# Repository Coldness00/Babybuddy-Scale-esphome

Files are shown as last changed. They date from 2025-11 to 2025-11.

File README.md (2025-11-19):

# 🍼 Smart Baby Bottle Scale  
### Measure every feeding automatically — ESP32 + ESPHome + Home Assistant + BabyBuddy  
<div align="center">
  
**Fully 3D‑printed • Open‑source • Wifi‑connected • Accurate to the gram**

</div>

---

## 🎯 Overview

This project is a **smart baby bottle scale** built with:

- an **ESP32‑S3**,  
- an **HX711 load cell amplifier**,  
- a **load cell**,  
- an **OLED display**,  
- RGB LEDs,  
- and **ESPHome**.

It automatically measures how much your baby drinks and sends the result directly to **Home Assistant**, which then creates a feeding entry in **BabyBuddy**.

Everything is fully autonomous, compact, and 3D‑printed.

---

## 🧩 Features

- **Accurate milk consumption tracking** (using calibrated load cell + HX711)
- **Automatic BabyBuddy feeding logs** through Home Assistant
- 3D‑printed enclosure (Bambu Studio `.3mf` included)
- **OLED screen** showing:
  - Bottle weight
  - Consumption
  - Last feeding time
  - Time since last feeding  
- **RGB LED feedback**
  - White fade in → bottle placed  
  - Yellow fade out → feeding started  
  - Green fade out → feeding finished  
  - Red pulse → error or invalid state  
- **Two physical buttons**
  - FULL → marks the bottle before feeding
    When pressed a circle is drawn on the top right corner of the screen
  - EMPTY → marks the bottle after feeding
  - When pressed the circle on the top right corner of the screen disappears
- **Static IP + fallback Wi‑Fi AP**
- **State restored after reboot** (timestamps, full weight, etc.)

---

## 🛒 Bill of Materials (BOM)

### Electronics

| Item | Description | Link |
|---|---|---|
| Load Cell + HX711 Kit | 50kg scale sensor with amplifier | https://fr.aliexpress.com/item/1005006165499175.html |
| ESP32‑S3 DevKitC‑1 | Main controller running ESPHome | - |
| SSD1306 OLED (128×64) | I²C display | https://fr.aliexpress.com/item/1005006262908701.html |
| WS2812 RGB LED strip | 3 LEDs | — |
| 2× Momentary push buttons | FULL + EMPTY | — |
| 8× M3 screws | — |

### 3D‑Printed Parts
- Complete `.3mf` Bambu Studio project included
- https://makerworld.com/en/models/2016578-babybuddy-scale#profileId-2172857
- Supports:
  - Load cell mount  
  - Front panel for OLED + buttons  
  - Compartment for ESP32 + HX711  



---

## 📸 Photos  





---

## 📡 How It Works

### 1. Press **FULL** before feeding  
- Weight is stored as “full bottle”  
- Timestamp saved  
- Yellow LED effect  
- Display shows full bottle icon  

### 2. Press **EMPTY** after feeding  
- New weight measured  
- Consumption is calculated  
- Data is sent to Home Assistant  
- Green LED effect  

### 3. Home Assistant Automation  
Home Assistant receives the values and automatically calls the **BabyBuddy API** to create a feeding entry (Formula / Bottle).

---

## 📦 ESPHome YAML Configuration

Full ESPHome config used in this project is available here:

`/esphome/biberon.yaml`

It includes:
- I²C OLED setup  
- HX711 calibration table  
- RGB LED effects  
- State persistence  
- Two GPIO buttons (full/empty)  
- Consumption calculation logic  
- Timestamp handling via Home Assistant time source  

---

## 🏠 Home Assistant Automation

Place this YAML inside your HA automations and edit accordingly the device_id:

```yaml
alias: Baby feeding bottle
description: ""
triggers:
  - trigger: state
    entity_id: sensor.biberon_bottle_consumption

conditions:
  - condition: template
    value_template: >
      {{ states('sensor.biberon_bottle_full_button_last_press') not in
         ['unknown','unavailable',''] and
         states('sensor.biberon_bottle_empty_button_last_press') not in
         ['unknown','unavailable',''] }}

  - condition: template
    value_template: >
      {{ states('sensor.biberon_bottle_consumption') | int(0) > 0 }}

actions:
  - delay: "00:00:02"
  - action: babybuddy.add_feeding
    target:
      device_id: 51762e63db1082c325ccfa7d02a4f4d6
    data:
      type: Formula
      method: Bottle
      start: "{{ states('sensor.biberon_bottle_full_button_last_press') }}"
      end: "{{ states('sensor.biberon_bottle_empty_button_last_press') }}"
      amount: "{{ states('sensor.biberon_bottle_consumption') | int(0) }}"

mode: queued
```

---

## 🧪 Calibration

Load cell calibration is performed using ESPHome’s `calibrate_linear` filter.  
You can recalibrate using known weights, then update the YAML accordingly.

---

## 📁 Project Structure

```
enclosure.3mf
biberon.yaml
README.md
LICENSE
```

---

## ❤️ Why I built this

Feeding logs are incredibly useful for newborns, but typing them manually is tedious.  
This project removes all friction by logging feedings **automatically** and accurately.

---

## 🙌 Contributions Welcome

Feel free to open issues or PRs if you'd like to improve the design, YAML, or integration.

---

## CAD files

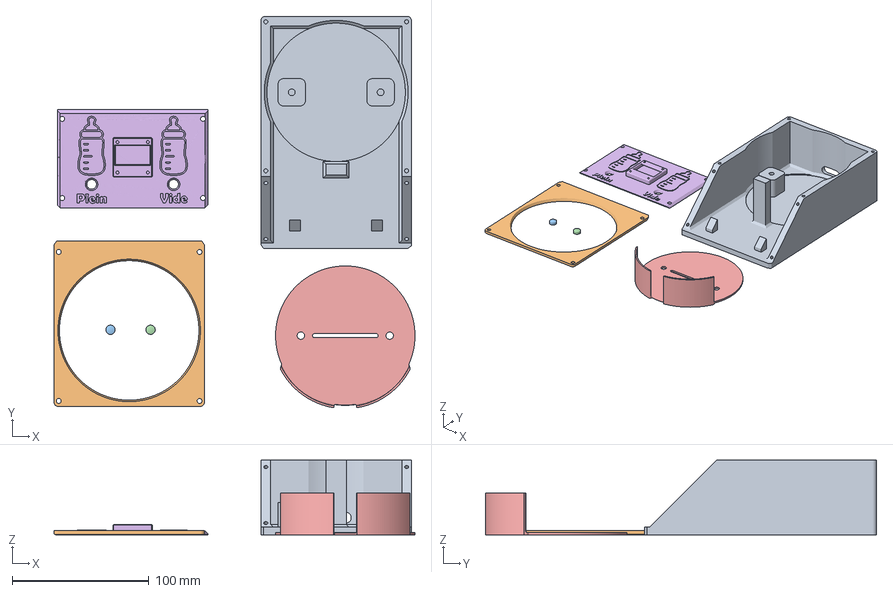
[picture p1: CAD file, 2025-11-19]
AssemScale.3MF
264.1 x 286.3 x 54.5 mm
AssemScale_2
AssemScale_3
button.STEP x 2
Disque
Assembly

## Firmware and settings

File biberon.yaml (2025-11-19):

esphome:
  name: biberon
  friendly_name: biberon
  on_boot:
    priority: -100
    then:
      - text_sensor.template.publish:
          id: full_button_last_time
          state: !lambda 'return id(stored_full_button_time);'
      - text_sensor.template.publish:
          id: empty_button_last_time
          state: !lambda 'return id(stored_empty_button_time);'

esp32:
  board: esp32-s3-devkitc-1
  framework:
    type: esp-idf

# Enable logging
logger:

# Enable Home Assistant API
api:
  encryption:
    key: "PM84lZ3RFLVo9WYZXQVOq1F+IAPQLBlbQGZICfo1av0="

ota:
  - platform: esphome
    password: "86cd421d5b7267d4cc3b7062481c7f5c"

wifi:
  ssid: !secret wifi_ssid
  password: !secret wifi_password
  manual_ip:
    static_ip: 192.168.1.36
    gateway: 192.168.1.254
    subnet: 255.255.255.0
  # Enable fallback hotspot (captive portal) in case wifi connection fails
  ap:
    ssid: "Biberon Fallback Hotspot"
    password: "SRzkIE3ZinEe"

bluetooth_proxy:
  active: true

captive_portal:

time:
  - platform: homeassistant
    id: ha_time
    timezone: Europe/Paris

globals:
  - id: weight_threshold
    type: float
    initial_value: '10.0'
    restore_value: true
  - id: button_pressed
    type: bool
    initial_value: 'false'
  - id: bottle_full_weight
    type: float
    initial_value: '0.0'
    restore_value: true
  - id: bottle_full_measured
    type: bool
    initial_value: 'false'
    restore_value: true
  - id: fed_measured
    type: bool
    initial_value: 'false'
    restore_value: true
  - id: showing_error
    type: bool
    initial_value: 'false'
  - id: stored_full_button_time
    type: std::string
    restore_value: yes
    initial_value: '"unknown"'
  - id: stored_empty_button_time
    type: std::string
    restore_value: yes
    initial_value: '"unknown"'



i2c:
  sda: GPIO16
  scl: GPIO15
  frequency: 20000Hz
  scan: true
  id: bus_a

display:
  - platform: ssd1306_i2c
    model: "SSD1306 128x64"
    address: 0x3C
    update_interval: 1s
    lambda: |-
      static unsigned long last_on_time = 0;
      static bool display_should_be_on = false;
      float weight = id(bottle_weight).state;
      if (weight > 5.0) {
        // Weight detected - show content
        display_should_be_on = true;
        last_on_time = millis();
        it.clear();
        it.printf(0, 0, id(font_fin), "Poids:");
        it.printf(0, 14, id(font_large), "%.0f g", weight);
        if (id(bottle_full_measured)) {
          it.filled_circle(it.get_width() - 4, 4, 3);
        }
        // Show last consumption with time elapsed
        if (id(bottle_consumption).has_state()) {
          float last_consumption = id(bottle_consumption).state;
          if (!std::isnan(last_consumption) && 
              !std::isinf(last_consumption) && 
              last_consumption > 0) {
            // Calculate time elapsed since empty button press
            auto current_time = id(ha_time).now();
            if (current_time.is_valid() && id(stored_full_button_time) != "unknown") {
              // Parse stored time
              struct tm stored_tm = {};
              strptime(id(stored_full_button_time).c_str(), "%Y-%m-%d %H:%M:%S", &stored_tm);
              time_t stored_epoch = mktime(&stored_tm);
              time_t current_epoch = current_time.timestamp;
              int elapsed_seconds = current_epoch - stored_epoch;
              int hours = elapsed_seconds / 3600;
              int minutes = (elapsed_seconds % 3600) / 60;
              if (hours > 0) {
                it.printf(0, 50, id(font_fin), "Bib': %.0fg - %dh%02d", last_consumption, hours, minutes);
              } else {
                it.printf(0, 50, id(font_fin), "Bib': %.0fg - %dmin", last_consumption, minutes);
              }
            } else {
              it.printf(0, 50, id(font_fin), "Bib': %.0f g", last_consumption);
            }
          }
        }
      } else if (display_should_be_on && (millis() - last_on_time > 10000)) {
        // No weight for 10 seconds - clear display
        display_should_be_on = false;
        it.clear();
      }

font:
  - file: "gfonts://Roboto"
    id: font_fin
    size: 12
  - file: "gfonts://Roboto"
    id: font_large
    size: 30

text_sensor:
  - platform: template
    id: full_button_last_time
    name: "Bottle Full Button Last Press"
    icon: mdi:clock-time-four-outline
    #update_interval: never

  - platform: template
    id: empty_button_last_time
    name: "Bottle Empty Button Last Press"
    icon: mdi:clock-time-four-outline
    #update_interval: never

number:
  - platform: template
    name: "Weight Threshold"
    id: weight_threshold_setting
    min_value: 0
    max_value: 1000
    step: 1
    unit_of_measurement: "g"
    mode: box
    initial_value: 10
    restore_value: true
    optimistic: true
    on_value:
      then:
        - globals.set:
            id: weight_threshold
            value: !lambda 'return x;'
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
